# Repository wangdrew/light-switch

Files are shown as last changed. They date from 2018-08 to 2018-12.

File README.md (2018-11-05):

# light-switch
Control your lights (and other smart home devices) with an internet-connected button board!

I'm lazy and I hate getting out of bed to turn off the lights. I bought a [Wink Hub](https://www.wink.com/products/wink-hub-2/) and some [Z-wave switches](http://amzn.to/2EEIUkB) which turn my lights into "smart" lights that I can control with my phone. Not having to get out of bed is a step in the right direction, but pulling out my phone, unlocking it, finding the app, and turning off the correct lights is still not convenient! And using a smart speaker such as Amazon Echo or Google Home isn't always great because your voice commands may disturb someone sleeping. 

So I'm taking it a step further by building an internet-connected button board using the [Spark Photon](https://www.particle.io/products/hardware/photon-wifi) that sits next to my bed. The Photon makes requests to the [Wink API](https://winkapiv2.docs.apiary.io) to manipulate the state of my smart home devices - such as controlling the lights. Now I can tap a button on the button board, and the Spark Photon inside makes an authenticated request to the Wink's servers which commands my Wink Hub to turn the lights turn off! This may be the most technologically complex solution to do something stupidly simple - but it works great! 

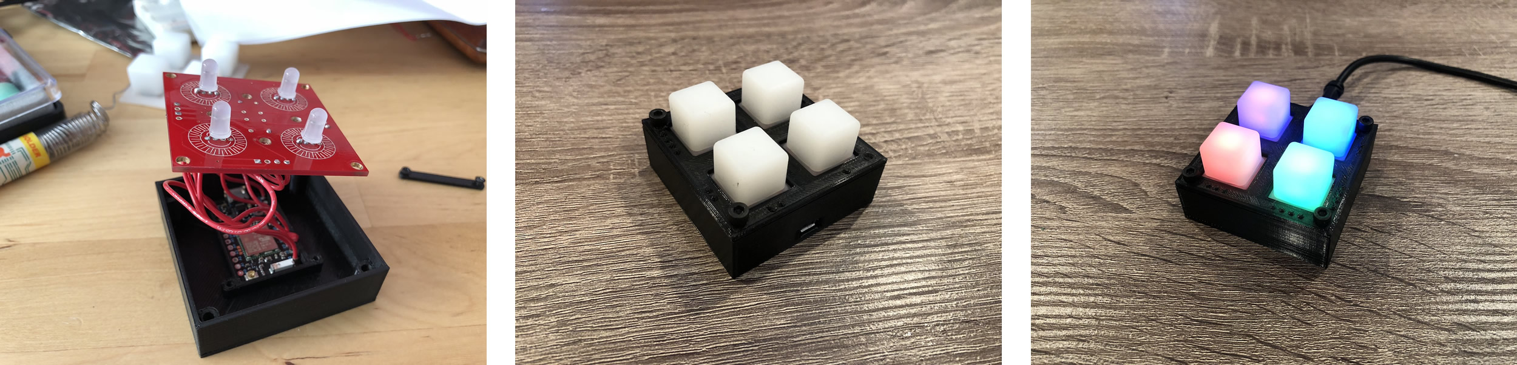
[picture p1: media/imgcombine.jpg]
light switch button board

## Hardware:
Some prerequisite hardware is required:
* Wink Hub 2 
* some "smart" devices to be controlled - Hue light bulbs, smart switches/outlets etc.
* Some compute resource (desktop computer, AWS, raspberry Pi etc.) capable of running Docker containers (more about this in a second)

For the button board, I opted for something with 4 buttons arranged in a 2x2 grid:
* [Spark Photon](http://amzn.to/2EEqdx6) - $19
* [2x2 button pad PCB](https://www.sparkfun.com/products/9277) - $5
* [2x2 button pad](https://www.sparkfun.com/products/7836) - $3
* [Some RGB LEDs to make it look cool](https://www.sparkfun.com/products/12986) - $3
* 3D printed case (~6m of 1.75mm PLA filament) - < $1
* 2 x M2x3mm and 4x M3x8mm screws- < $1

Cost of the button board: $32 (excluding all the smart home stuff above)

See [hardware/README.md](hardware/README.md) for assembly instructions and 3D printable STL files.

## Design:
There are 2 software components to this system:
* The Spark Photon .ino sketch which makes HTTP REST calls to a middleware server on the local network
* A middleware HTTP server written for Python 2.7 with [Falcon](https://falcon.readthedocs.io/en/stable/index.html) and [Gunicorn](http://gunicorn.org/) running in a docker container. Wraps the Photon's HTTP requests with Wink required authentication and forwards the request and response to/from the Wink API. 

## Limitations
I originally wanted the Spark Photon to communicate directly with the Wink API but this isn't possible because while the Spark Photon does support TCP/HTTP, there is no software support for SSL meaning it is unable to make HTTPS calls required by the Wink API. The middleware server wraps the Wink API and exposes an HTTP interface on the local network for the Spark Photon. It also handles Wink API authentication and refreshes the Wink access token. The local API it exposes is thus unencrypted and unauthenticated.

The middleware server requires you to first obtain an access token and refresh token from Wink's oAuth endpoint as the server doesn't host the oAuth flow required to exchange Wink user credentials and auth code for the access/refresh tokens. See below for steps

## Getting Started
1) Request and wait for [Wink API developer credentials](https://developer.wink.com/)
2) With the granted Client ID and Client Secret, exchange these for an authorization code by using a browser to navigate to:
```
https://api.wink.com/oauth2/authorize?client_id=$CLIENT_ID&redirect_uri=$REDIRECT_URI
```
3) In the browser, login with Wink user account credentials. The browser will redirect to `$REDIRECT_URI`. The authorization code will be appended as a URL query param. Copy and paste this.
4) cURL the Wink oAuth endpoint to retrieve access and refresh tokens
```
curl -X POST \
  https://api.wink.com/oauth2/token \
  -H 'Content-Type: application/json' \
  -d '{
  "client_secret": "'$CLIENT_SECRET'",
  "grant_type": "authorization_code",
  "code": "'$AUTH_CODE'"
}'
```
The response contains the access and refresh tokens.

5) Run the middleware server and specify your client secret, access and refresh tokens. Specify a port for the server to bind to. 8000 is default, I have mine specified as 4200.
```
docker pull wangdrew/lightswitch
docker run -e "CLIENT_ID=" -e "CLIENT_SECRET=" -e "ACCESS_TOKEN=" -e "REFRESH_TOKEN=" -p 8000:8000 -d lightswitch:latest
```

6) Use the [Web Particle IDE](https://build.particle.io/build), copy and paste the code from `/particle` into the web editor. You will need to change `serverHostname` and `serverPort` to be the hostname and port of the local middleware server. Flash the code onto the Spark Photon.

## Building the server:
To build a new docker image after modifying the server:
```
docker build -t lightswitch:latest .
```

## Testing the server locally:
To run the server locally, first activate the python virtualenv:
```
source .venv/bin/activate
```

If this is the first time starting the environment, install the dependencies:
```
pip install -r requirements.txt
```
Ensure `light-switch/credentials.json` has the correct tokens and secrets. Then start the gunicorn server:
```
gunicorn -b 0.0.0.0:8000 light-switch.app
```
After closing the server, deactivate the virtualenv with:
```
deactivate
```

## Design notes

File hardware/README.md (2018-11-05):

# Assembling the button board
The button board consists of 4 main parts:
* Spark Photon
* Sparkfun-branded 2x2 button pad PCB with 4 WS8212 RGB LEDs
* Rubbery 2x2 button pad buttons
* 3D printed case

## Printing the case
If you've got a 3D printer - great! If not, anything that can fit the components and hold the button board in place will work too. I used a Pepero box with X-acto cutouts as a prototype.

The case comes in two STL files:
 * [light-switch-case-v3.stl](stl/light-switch-case-v3.stl) which contains the case and a small lock arm to keep the Photon snug and in-place
 * [light-switch-top.stl](stl/light-switch-top.stl) which is just the top plate that goes over the button pad

Print settings used for both files:
* PLA (200 °C extruder / 60 °C bedplate)
* 0.2mm resolution
* 30% infill (doesn't really matter since the design is all "walls")
* Enable supports (tiny bit needed for the USB hole)
* No rafts

## Soldering the PCB
Unfortunately the [Sparkfun 2x2 button PCB](https://www.sparkfun.com/products/9277) doesn't support individually addressable LEDs and instead supports only the analog LEDs that have a pins for R, G, B and ground. I modified the PCB by scratching out PCB traces and adding additional connections to support the WS8212 addressable LEDs.

Yellow X's are traces that need to be disconnected by scratching out the underlying metal trace. Use a multimeter to double check that there's no connectivity. Green lines represent new connections that need to be soldered together. 

Only three connections to the Photon board from the PCB are required now: Din (formerly "Green" pin), Vcc (formerly "Blue" pin), and Ground (still "LED-Ground" pin).

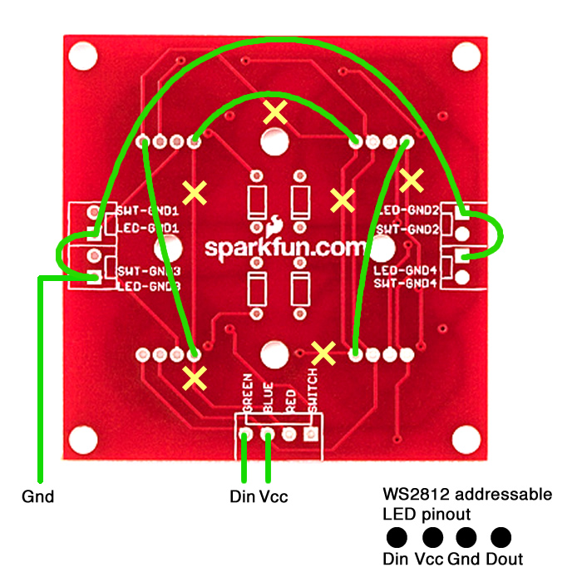
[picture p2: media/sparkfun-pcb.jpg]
PCB diagram


## Final assembly

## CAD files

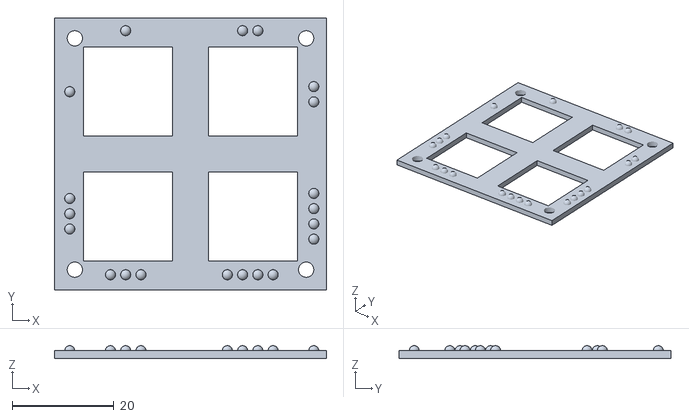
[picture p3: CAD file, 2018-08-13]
hardware/stl/light-switch-top.stl
53.5 x 53.5 x 2.50

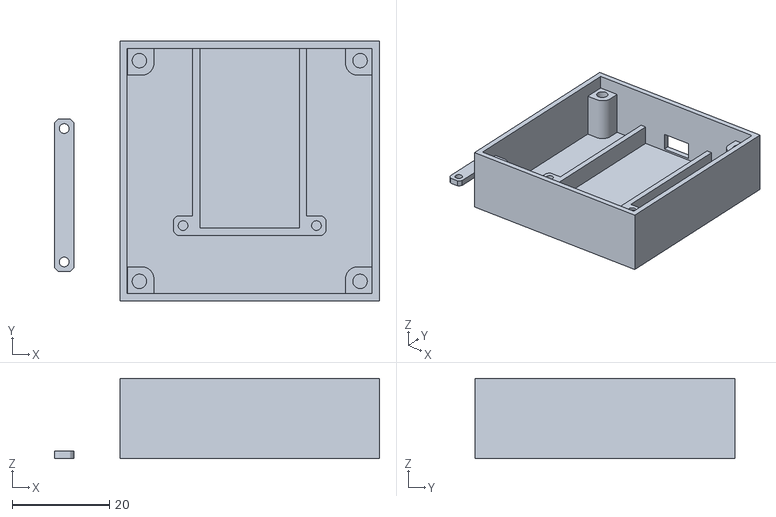
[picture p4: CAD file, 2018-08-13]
hardware/stl/light-switch-case-v3.stl
67.0 x 53.5 x 16.5

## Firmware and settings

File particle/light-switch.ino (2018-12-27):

// This #include statement was automatically added by the Particle IDE.
#include <neopixel.h>

// This #include statement was automatically added by the Particle IDE.
#include "rest_client.h"

#define BUTTON0 D0
#define BUTTON1 D1
#define BUTTON2 D2
#define BUTTON3 D3

#define PIXEL_PIN D6
#define PIXEL_COUNT 4
#define PIXEL_TYPE WS2812B
#define BRIGHTNESS 32  // 0 - 255

// Something in the code is blocking and causing the photon to
// breathe green because it no longer connects to Particle cloud.
// Do particle cloud stuff in a separate thread and try to debug
// where the code freezes with the web console
SYSTEM_THREAD(ENABLED);

bool DEBUG_LOG = true;
char* serverHostname = "192.168.69.3";
int serverPort = 4200;

char photonName[32] = "";

RestClient client = RestClient(serverHostname, serverPort);

Adafruit_NeoPixel strip(PIXEL_COUNT, PIXEL_PIN, PIXEL_TYPE);

char* photon2Config[4][3] = {
    {"POST","/wink/groups/6870297/activate",
        "{\"desired_state\": {\"powered\": false}}"},
    {"PUT","/wink/binary_switches/370507/desired_state",
        "{\"desired_state\":{\"powered\":true}}"},
    {"PUT", "/wink/light_bulbs/2376917/desired_state",
        "{\"desired_state\": {\"powered\": true, \"brightness\": 1.00, \"color_model\": \"color_temperature\", \"color_temperature\": 3000}}"},
    {"PUT", "/wink/light_bulbs/2376917/desired_state",
        "{\"desired_state\": {\"powered\": true, \"brightness\": 0.40, \"color_model\": \"color_temperature\", \"color_temperature\": 2500}}"}
};

char* photon3Config[4][3] = {
    {"POST","/wink/groups/11886987/activate",
        "{\"desired_state\":{\"powered\":false}}"},
    {"PUT","/wink/light_bulbs/3676075/desired_state",
        "{\"desired_state\": {\"powered\": false}}"},
    {"PUT", "/wink/light_bulbs/3676075/desired_state",
        "{\"desired_state\":{\"powered\":true, \"brightness\":1.00}}"},
    {"PUT", "/wink/light_bulbs/3676075/desired_state",
        "{\"desired_state\":{\"powered\": true, \"brightness\":0.05}}"}
};


void saveName(const char *topic, const char *data) {
    strncpy(photonName, data, sizeof(photonName)-1);
    Serial.println("received " + String(topic) + ": " + String(data));
}

void setup() {
    Serial.begin(9600);
    Serial.println("Starting...");
    
    pinMode(BUTTON0, INPUT_PULLUP);
    pinMode(BUTTON1, INPUT_PULLUP);
    pinMode(BUTTON2, INPUT_PULLUP);
    pinMode(BUTTON3, INPUT_PULLUP);
    
    strip.begin();
    strip.setBrightness(BRIGHTNESS);

    waitUntil(Particle.connected);

    // do something cool when everything's set up
    rainbowCycle(3);
    lightsOff();
    Particle.subscribe("particle/device/name", saveName);
    Particle.publish("particle/device/name");  // ask the cloud for the name to be sent to you
}

int makeRequest(char* method, char* url, char* body) {
    String response = "";
    int statusCode;
    if (strcmp(method, "POST") == 0) {
        statusCode = client.post(url, body, &response);
    } else {
        statusCode = client.put(url, body, &response);
    }
    if (DEBUG_LOG) {
        Particle.publish("LightSwitch", 
            String::format("Status Code: %d, Response: %s", statusCode, response.c_str()), 60, PRIVATE);
    }
    return statusCode;
}

int request(int button) {
    int statusCode;
    if (strcmp(photonName, "photon-3") == 0) {
        statusCode = makeRequest(photon3Config[button][0], photon3Config[button][1], photon3Config[button][2]);
    } else {
        statusCode = makeRequest(photon2Config[button][0], photon2Config[button][1], photon2Config[button][2]);
    }
    return statusCode;
}

void loop() {
    if (digitalRead(BUTTON0) == LOW) {
        lightUpRequestMade(2);

        int statusCode = request(BUTTON0);
        lightUpRequestComplete(2, isRequestSuccess(statusCode));
    }

    else if (digitalRead(BUTTON1) == LOW) {
        lightUpRequestMade(1);
        int statusCode = request(BUTTON1);
        lightUpRequestComplete(1, isRequestSuccess(statusCode));
    }
    
    else if (digitalRead(BUTTON2) == LOW) {
        lightUpRequestMade(3);
        int statusCode = request(BUTTON2);
        lightUpRequestComplete(3, isRequestSuccess(statusCode));
    }
    
    else if (digitalRead(BUTTON3) == LOW) {
        lightUpRequestMade(0);
        int statusCode = request(BUTTON3);
        lightUpRequestComplete(0, isRequestSuccess(statusCode));
    }
}

bool isRequestSuccess(int statusCode) {
    return statusCode >= 200 && statusCode < 299;
}

void lightUpRequestMade(int pixel) {
    strip.setPixelColor(pixel, strip.Color(64, 128, 0)); // orange
    strip.show();
}

void lightUpRequestComplete(int pixel, bool success) {
    int numFlashes = 3;
    int delayMs = 50;
    uint32_t color = strip.Color(128, 0, 0); // green
    if (!success) {
        delayMs = 400;
        color = strip.Color(0, 255, 0); // red
    }
    
    for (int i=0; i<numFlashes; i++) {
        strip.setPixelColor(pixel, color);
        strip.show();
        delay(delayMs);
        strip.setPixelColor(pixel, strip.Color(0, 0, 0)); // off
        strip.show();
        if (i < numFlashes-1) {
            delay(delayMs);
        } 
    }
}

void lightsOff() {
    for (int i=0; i<PIXEL_COUNT; i++) {
        strip.setPixelColor(i, strip.Color(0, 0, 0));
    }
    strip.show();
}

/**
* This stuff is copied from neopixel examples
*/
// Slightly different, this makes the rainbow equally distributed throughout, then wait (ms)
void rainbowCycle(uint8_t wait) {
  uint16_t i, j;

  for(j=0; j<256; j++) { // 1 cycle of all colors on wheel
    for(i=0; i< strip.numPixels(); i++) {
      strip.setPixelColor(i, Wheel(((i * 256 / strip.numPixels()) + j) & 255));
    }
    strip.show();
    delay(wait);
  }
}

// Input a value 0 to 255 to get a color value.
// The colours are a transition r - g - b - back to r.
uint32_t Wheel(byte WheelPos) {
  if(WheelPos < 85) {
   return strip.Color(WheelPos * 3, 255 - WheelPos * 3, 0);
  } else if(WheelPos < 170) {
   WheelPos -= 85;
   return strip.Color(255 - WheelPos * 3, 0, WheelPos * 3);
  } else {
   WheelPos -= 170;
   return strip.Color(0, WheelPos * 3, 255 - WheelPos * 3);
  }
}

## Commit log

2018-08-13 add 3d printing stls
    [light-switch-case-v3.stl, light-switch-top.stl]
2018-08-15 flash red on error
    [light-switch.ino]
2018-08-15 add sparkfun pcb image
2018-11-05 update jpg wiring diagram
2018-11-05 mulitple light-switch unit support
